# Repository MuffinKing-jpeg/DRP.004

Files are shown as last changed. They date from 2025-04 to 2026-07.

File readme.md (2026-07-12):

# DRP.004

Quack with the **new level**!
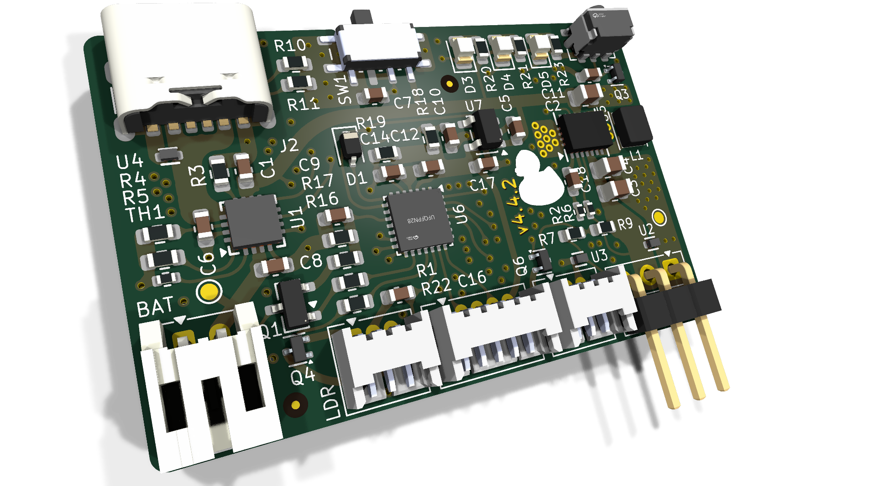
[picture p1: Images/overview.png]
bottom image


## Docs

- [Interactive BOM](./Docs/ibom.html)
- [Schematics](./Docs/DRP.004.pdf)
- [Production files](./production/)

## Changes in v3

- Completely new power design
  - 1.8v for MCU + LDR
  - ~5.5v for servo only
- Interface moved to one side.
- MOAR SILK!
- ENIG

## Changes in v4.2

- Switches moved to SMT parts
- Moved USB to same side as other user interfaces
- Changed battery connector to PH2.0
- Changed NTC thermistor to 0402
- Rerouted almost everything

## Changes in v4.3

- Threw to trash few useless resistors  
- Removed power-on by button
- Squished PCB to 27*42mm size  
- Fresh docs

## Changes in v4.4

- CI/CD
- TPS61022 -> TPS63020

## Issues to overcome

- [] Please works as v3

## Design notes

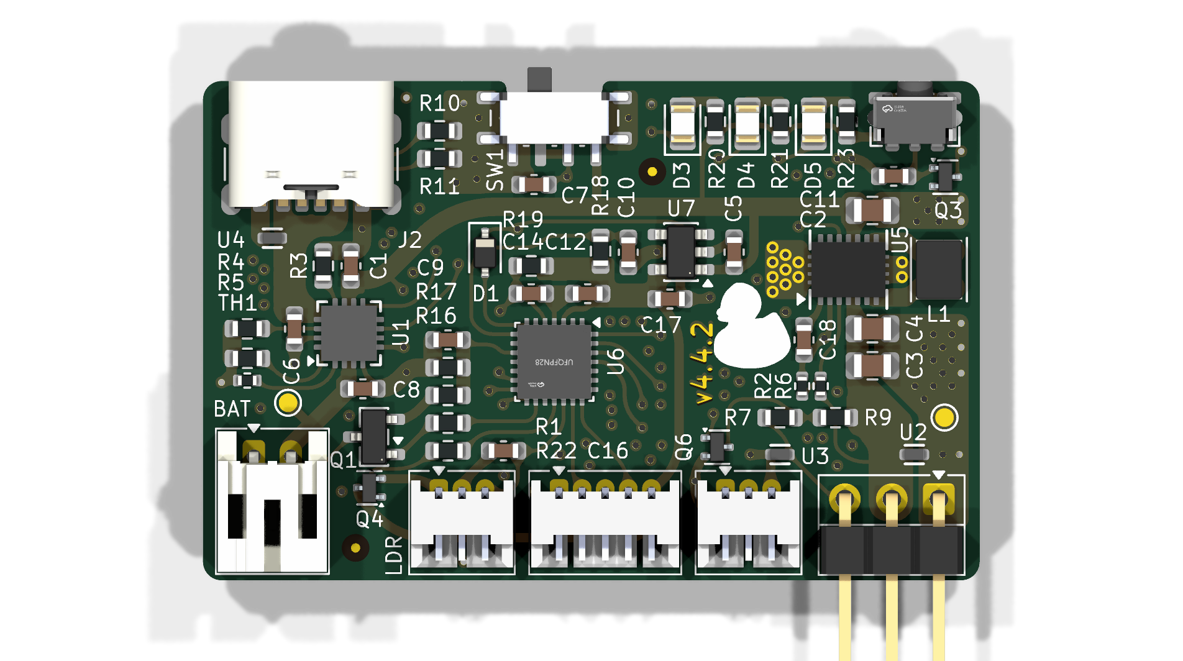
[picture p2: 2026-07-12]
Images/top.png

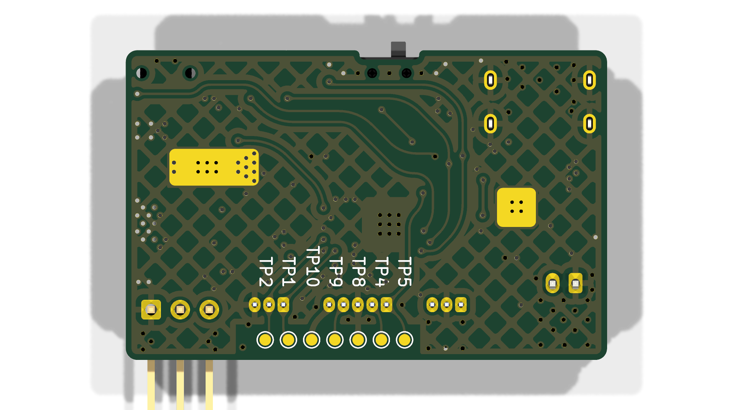
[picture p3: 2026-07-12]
Images/bot.png

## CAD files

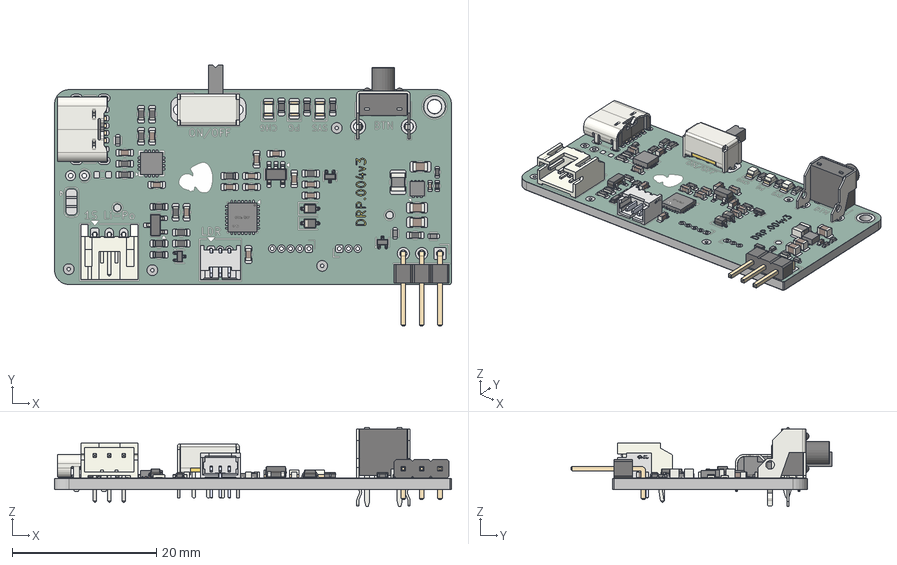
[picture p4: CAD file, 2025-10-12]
Mechanical/DRP.004.step
55.0 x 36.2 x 11.0 mm
C_0603_1608Metric x 13
R_0603_1608Metric x 17
UFQFPN-28_L4.0-W4.0-H0.6-P0.50
LED_0805_2012Metric x 3
LF x 3
CPD x 3
BODY-SON x 4
SW_Slide_SPDT_Angled_CK_OS102011MA1Q
C_0805_2012Metric x 3
CONN-TH_1.25T-3P-WP
SW_Tactile_SPST_Angled_PTS645Vx58-2LFS
USB_C_Receptacle_GCT_USB4125-xx-x-0190_6P_TopMnt_Horizontal
SOT-23
SOT-23-5
R_0402_1005Metric x 2
D_SOD-323 x 2
L_1008_2520Metric
C_0402_1005Metric
PinHeader_1x03_P2.54mm_Horizontal
JST_PH_S3B-PH-K_1x03_P2.00mm_Horizontal
BODY-QFN
PIN1-ID
DRP.004_copper
DRP.004_pad
DRP.004_via
DRP.004_silkscreen
DRP.004_soldermask
DRP.004_PCB

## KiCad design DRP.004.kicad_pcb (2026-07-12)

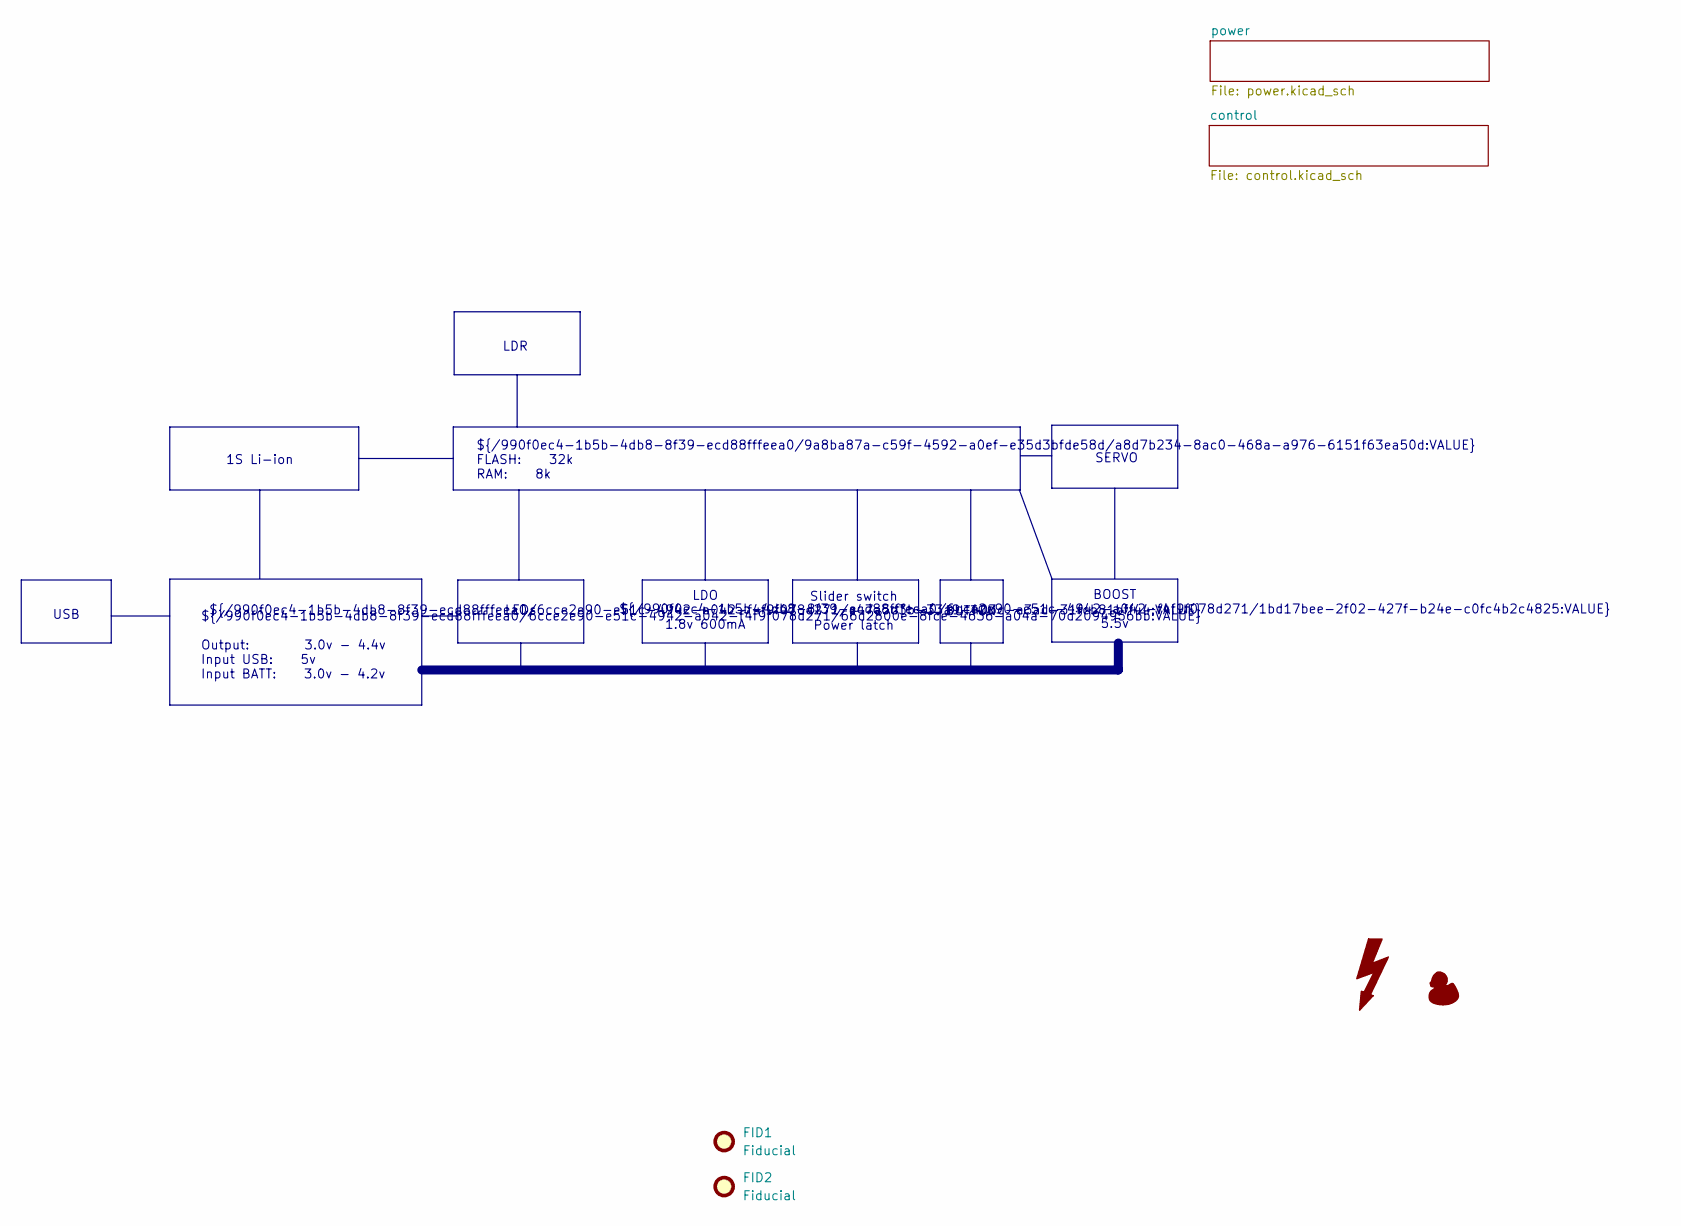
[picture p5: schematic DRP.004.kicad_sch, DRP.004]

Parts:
FID1, FID2: Fiducial; Fiducial_0.5mm_Mask1.5mm

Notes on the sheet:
Slider switch + Power latch
LEDs
SERVO
BOOST ${/990f0ec4-1b5b-4db8-8f39-ecd88fffeea0/6cce2e90-e51c-4942-a042-f4f9f078d271/1bd17bee-2f02-427f-b24e-c0fc4b2c4825:VALUE} 5.5v
USB
${/990f0ec4-1b5b-4db8-8f39-ecd88fffeea0/9a8ba87a-c59f-4592-a0ef-e35d3bfde58d/a8d7b234-8ac0-468a-a976-6151f63ea50d:VALUE} FLASH: 32k RAM: 8k
LDO ${/990f0ec4-1b5b-4db8-8f39-ecd88fffeea0/6cce2e90-e51c-4942-a042-f4f9f078d271/c47a5d3b-33a9-403c-a3ad-31fcb81bff44:VALUE} 1.8v 600mA
LDR
${/990f0ec4-1b5b-4db8-8f39-ecd88fffeea0/6cce2e90-e51c-4942-a042-f4f9f078d271/66d2800e-8fce-4636-a04a-70d2094956bb:VALUE} Output: 3.0v - 4.4v Input USB: 5v Input BATT: 3.0v - 4.2v
1S Li-ion
BUTTON

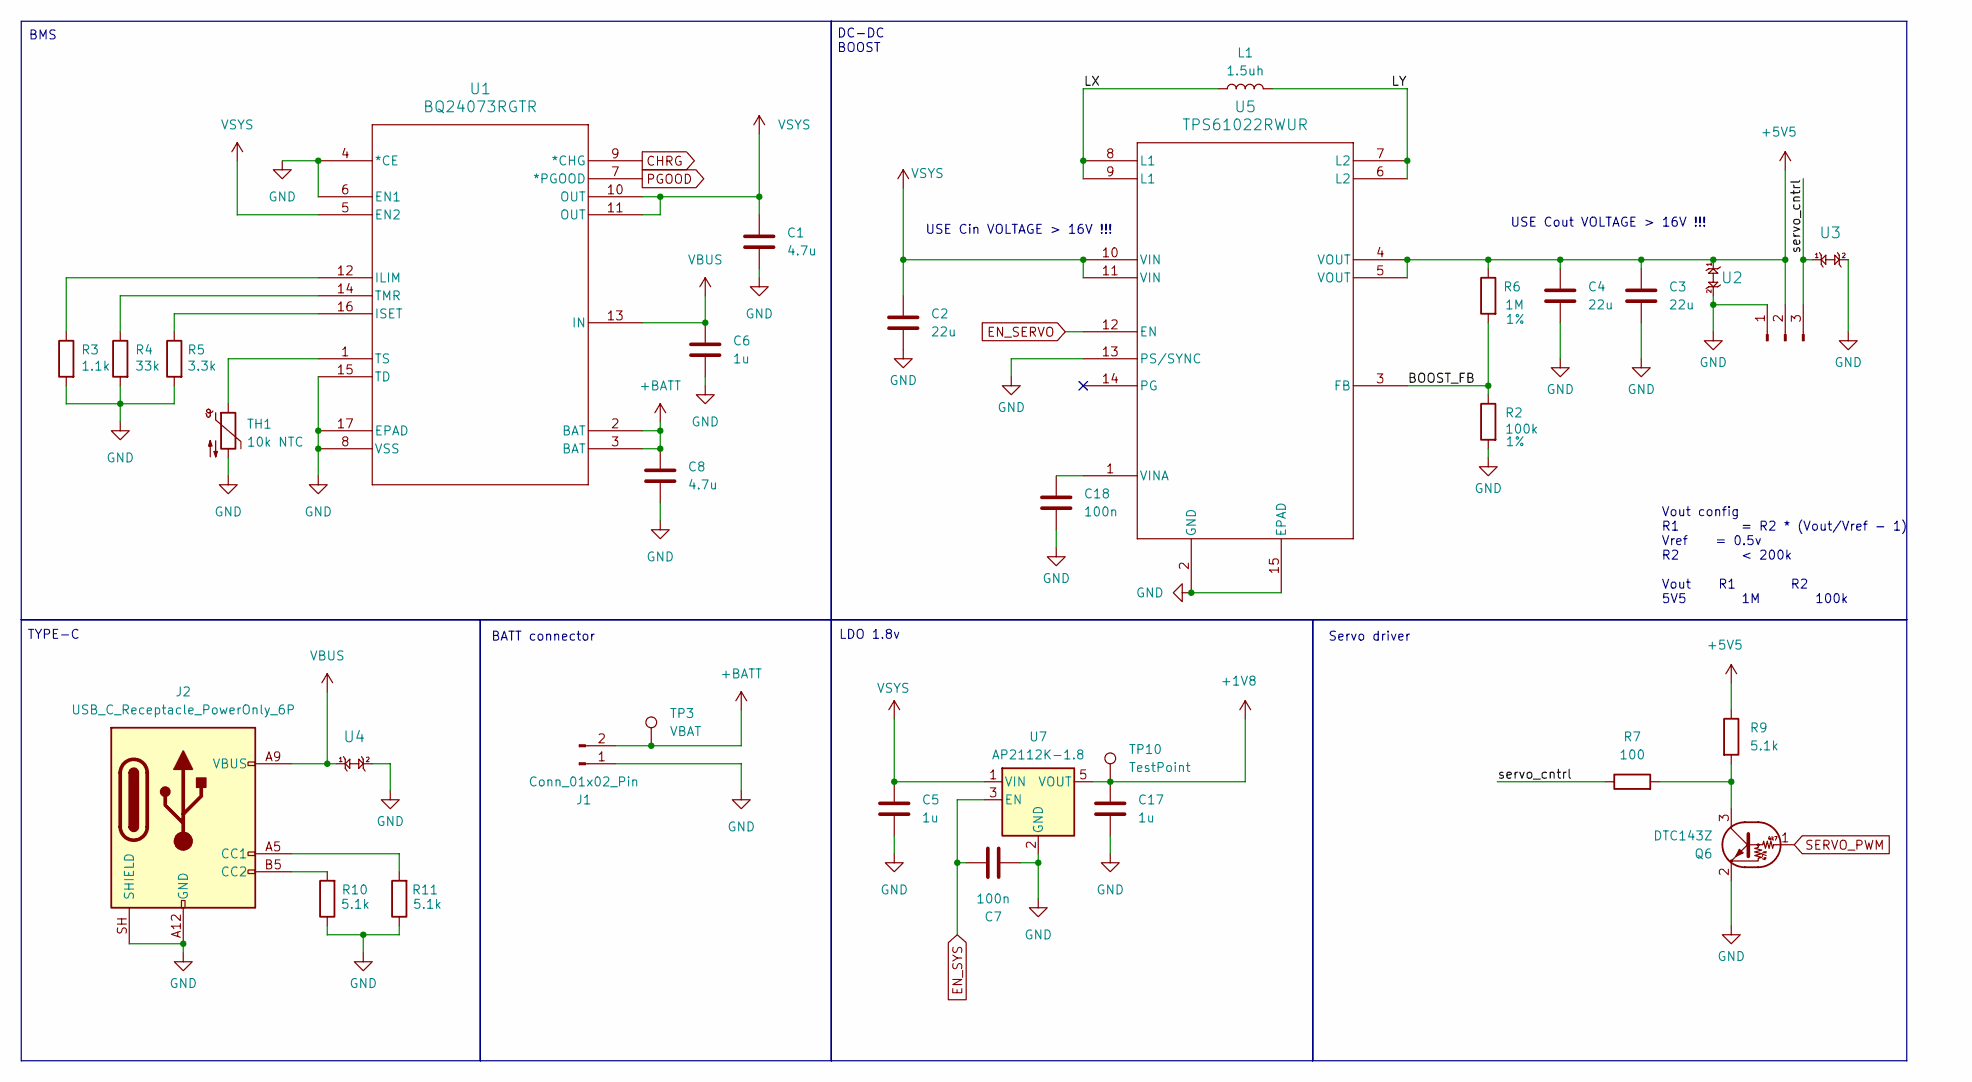
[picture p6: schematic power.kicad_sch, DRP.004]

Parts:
C1, C8: 4.7u; C_0603_1608Metric
C2, C3, C4: 22u; C_0805_2012Metric
C5, C6, C17: 1u; C_0603_1608Metric
C7, C18: 100n; C_0603_1608Metric
J1: Conn_01x02_Pin; JST_PH_S2B-PH-K_1x02_P2.00mm_Horizontal
J2: USB_C_Receptacle_PowerOnly_6P; USB_C_Receptacle_GCT_USB4125-xx-x-0190_6P_TopMnt_Horizontal
J3: Conn_01x03_Pin; PinHeader_1x03_P2.54mm_Horizontal
L1: 1.5uh; L_Changjiang_FTC322512S; LCSC C5179444
Q6: DTC143Z; SOT-523; LCSC C2828442
R2: 100k; R_0402_1005Metric; Tolerance 1%
R3: 1.1k; R_0603_1608Metric
R4: 33k; R_0603_1608Metric
R5: 3.3k; R_0603_1608Metric
R6: 1M; R_0402_1005Metric; Tolerance 1%
R7: 100; R_0603_1608Metric
R9, R10, R11: 5.1k; R_0603_1608Metric
TH1: 10k NTC; R_0402_1005Metric
TP3: VBAT; TestPoint_Pad_D1.0mm
TP10: TestPoint; TestPoint_Pad_D1.0mm
U1: BQ24073RGTR; RGT16; LCSC C15220
U2, U3, U4: TPD1E10B06DPYR; X1SON-2_L1.0-W0.6-P0.65-BI; LCSC C48260
U5: TPS61022RWUR; DSJ14_2P85X1P58; LCSC C15483
U7: AP2112K-1.8; SOT-23-5; LCSC C176944

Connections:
+1V8: C17.1, TP10.1 (1_1), U7.5 (VOUT); also elsewhere on the board
+5V5: C3.1, C4.1, J3.2, R6.1, R9.1, U2.1, U5.4 (VOUT), U5.5 (VOUT)
+BATT: C8.1, J1.2, TP3.1 (1_1), U1.2 (BAT), U1.3 (BAT); also elsewhere on the board
/power/BOOST_FB: R2.1, R6.2, U5.3 (FB)
/power/LX: L1.1, U5.8 (L1), U5.9 (L1)
/power/LY: L1.2, U5.6 (L2), U5.7 (L2)
/power/servo_cntrl: J3.3, R7.1, U3.1
CHRG: U1.9 (*CHG); also elsewhere on the board
EN_SERVO: U5.12 (EN); also elsewhere on the board
EN_SYS: C7.2, U7.3 (EN); also elsewhere on the board
GND: C1.2, C2.2, C3.2, C4.2, C5.2, C6.2, C7.1, C8.2, C17.2, C18.2, J1.1, J2.A12 (GND), J2.B12 (GND), J2.SH (SHIELD), J3.1, Q6.2 (E), R2.2, R3.2, R4.2, R5.2, R10.1, R11.1, TH1.2, U1.4 (*CE), U1.6 (EN1), U1.8 (VSS), U1.15 (TD), U1.17 (EPAD), U2.2, U3.2, U4.2, U5.2 (GND), U5.13 (PS/SYNC), U5.15 (EPAD), U7.2 (GND); also elsewhere on the board
unnamed: J2.A5 (CC1), R11.2
unnamed: J2.B5 (CC2), R10.2
unnamed: Q6.3 (C), R7.2, R9.2
unnamed: R3.1, U1.12 (ILIM)
unnamed: R5.1, U1.16 (ISET)
unnamed: R4.1, U1.14 (TMR)
unnamed: TH1.1, U1.1 (TS)
unnamed: C18.1, U5.1 (VINA)
PGOOD: U1.7 (*PGOOD); also elsewhere on the board
SERVO_PWM: Q6.1 (B); also elsewhere on the board
VBUS: C6.1, J2.A9 (VBUS), J2.B9 (VBUS), U1.13 (IN), U4.1
VSYS: C1.1, C2.1, C5.1, U1.5 (EN2), U1.10 (OUT), U1.11 (OUT), U5.10 (VIN), U5.11 (VIN), U7.1 (VIN); also elsewhere on the board

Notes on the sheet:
USE Cout VOLTAGE > 16V !!!
LDO 1.8v
DC-DC BOOST
TYPE-C
Servo driver
USE Cin VOLTAGE > 16V !!!
BMS
BATT connector
Vout config R1 = R2 * (Vout/Vref - 1) Vref = 0.5v R2 < 200k Vout R1 R2 5V5 1M 100k

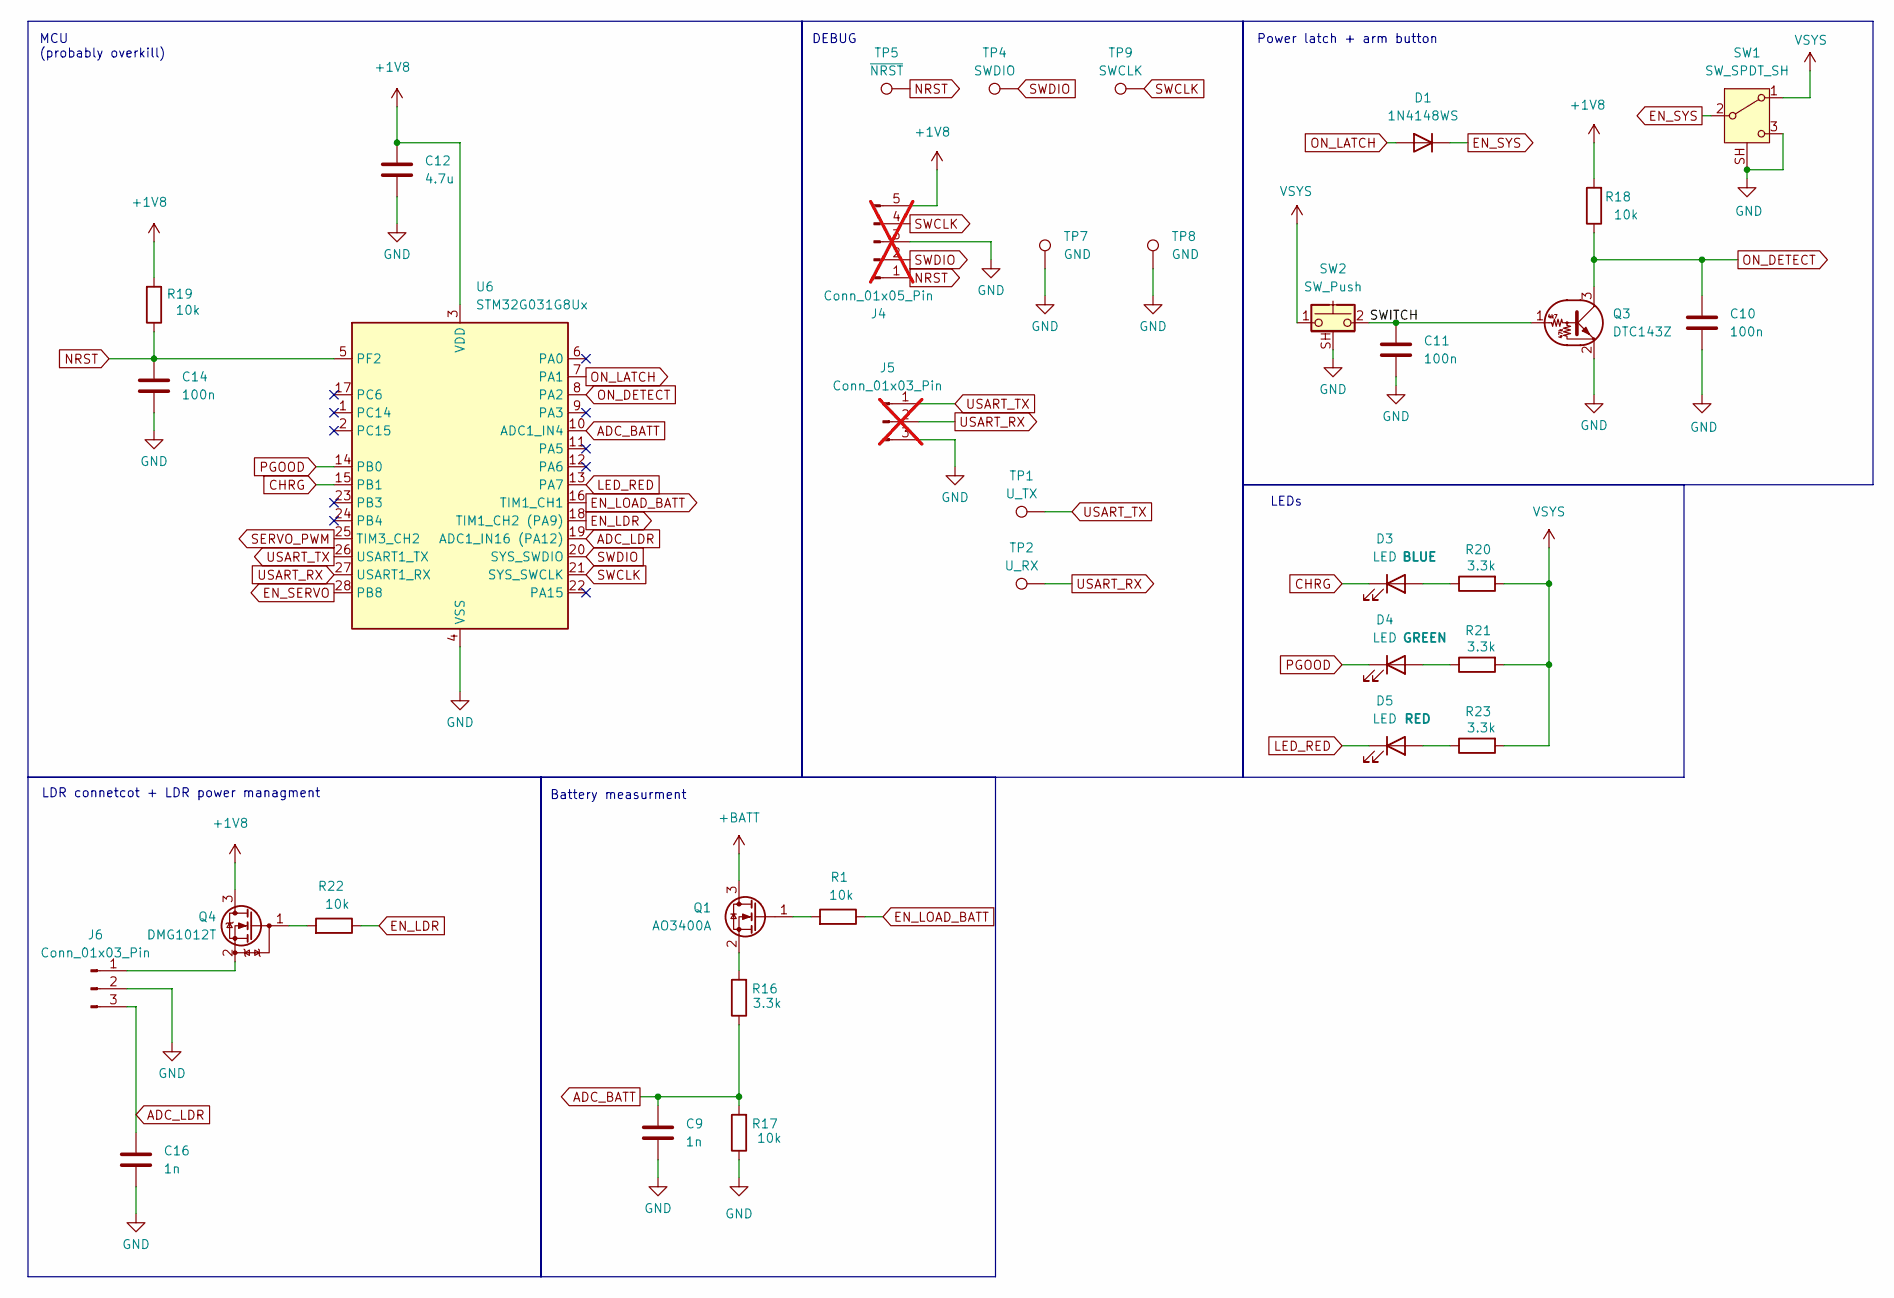
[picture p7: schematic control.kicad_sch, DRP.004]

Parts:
C9, C16: 1n; C_0603_1608Metric
C10, C11, C14: 100n; C_0603_1608Metric
C12: 4.7u; C_0603_1608Metric
D1: 1N4148WS; D_SOD-323; LCSC C6423741
D3, D4, D5: LED; LED_0805_2012Metric
J4: Conn_01x05_Pin; Molex_PicoBlade_53048-0510_1x05_P1.25mm_Horizontal; not fitted
J5: Conn_01x03_Pin; Molex_PicoBlade_53048-0310_1x03_P1.25mm_Horizontal; not fitted
J6: Conn_01x03_Pin; Molex_PicoBlade_53048-0310_1x03_P1.25mm_Horizontal
Q1: AO3400A; SOT-23
Q3: DTC143Z; SOT-523; LCSC C2828442
Q4: DMG1012T; SOT-523; LCSC C20512
R1, R17, R18, R19, R22: 10k; R_0603_1608Metric
R16, R20, R21, R23: 3.3k; R_0603_1608Metric
SW1: SW_SPDT_SH; MSK12C02; LCSC C109335
SW2: SW_Push; SW_Push_1P1T-MP_NO_Horizontal_Alps_SKRTLAE010; LCSC C398057
TP1: U_TX; TestPoint_Pad_D1.0mm
TP2: U_RX; TestPoint_Pad_D1.0mm
TP4: SWDIO; TestPoint_Pad_D1.0mm
TP5: ~{NRST}; TestPoint_Pad_D1.0mm
TP7, TP8: GND; TestPoint_Pad_D1.0mm
TP9: SWCLK; TestPoint_Pad_D1.0mm
U6: STM32G031G8Ux; QFN-28_4x4mm_P0.5mm; LCSC C432211

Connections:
+1V8: C12.1, J4.5, Q4.3 (D), R18.2, R19.2, U6.3 (VDD); also elsewhere on the board
+BATT: Q1.3 (D); also elsewhere on the board
/control/SWITCH: C11.1, Q3.1 (B), SW2.2
ADC_BATT: C9.1, R16.1, R17.2, U6.10 (ADC1_IN4)
ADC_LDR: C16.1, J6.3, U6.19 (ADC1_IN16 (PA12))
CHRG: D3.1 (K), U6.15 (PB1); also elsewhere on the board
EN_LDR: R22.1, U6.18 (TIM1_CH2 (PA9))
EN_LOAD_BATT: R1.1, U6.16 (TIM1_CH1)
EN_SERVO: U6.28 (PB8); also elsewhere on the board
EN_SYS: D1.1 (K), SW1.2 (B); also elsewhere on the board
GND: C9.2, C10.2, C11.2, C12.2, C14.2, C16.2, J4.3, J5.3, J6.2, Q3.2 (E), R17.1, SW1.3 (C), SW1.SH (Shield), SW2.SH (B), TP7.1 (1_1), TP8.1 (1_1), U6.4 (VSS); also elsewhere on the board
LED_RED: D5.1 (K), U6.13 (PA7)
NRST: C14.1, J4.1, R19.1, TP5.1 (1_1), U6.5 (PF2)
unnamed: D3.2 (A), R20.1
unnamed: D4.2 (A), R21.1
unnamed: D5.2 (A), R23.1
unnamed: J6.1, Q4.2 (S)
unnamed: Q1.1 (G), R1.2
unnamed: Q1.2 (S), R16.2
unnamed: Q4.1 (G), R22.2
ON_DETECT: C10.1, Q3.3 (C), R18.1, U6.8 (PA2)
ON_LATCH: D1.2 (A), U6.7 (PA1)
PGOOD: D4.1 (K), U6.14 (PB0); also elsewhere on the board
SERVO_PWM: U6.25 (TIM3_CH2); also elsewhere on the board
SWCLK: J4.4, TP9.1 (1_1), U6.21 (SYS_SWCLK)
SWDIO: J4.2, TP4.1 (1_1), U6.20 (SYS_SWDIO)
USART_RX: J5.2, TP2.1 (1_1), U6.27 (USART1_RX)
USART_TX: J5.1, TP1.1 (1_1), U6.26 (USART1_TX)
VSYS: R20.2, R21.2, R23.2, SW1.1 (A), SW2.1; also elsewhere on the board

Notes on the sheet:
MCU (probably overkill)
DEBUG
LEDs
LDR connetcot + LDR power managment
Power latch + arm button
Battery measurment

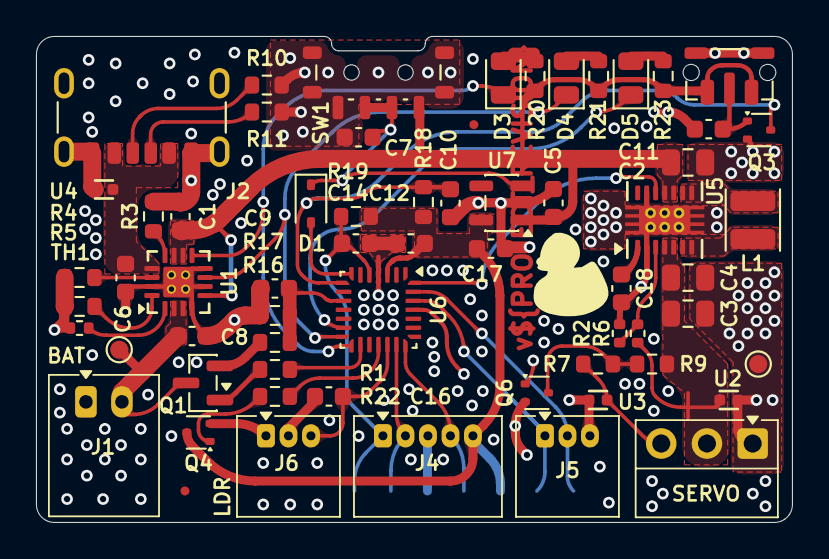
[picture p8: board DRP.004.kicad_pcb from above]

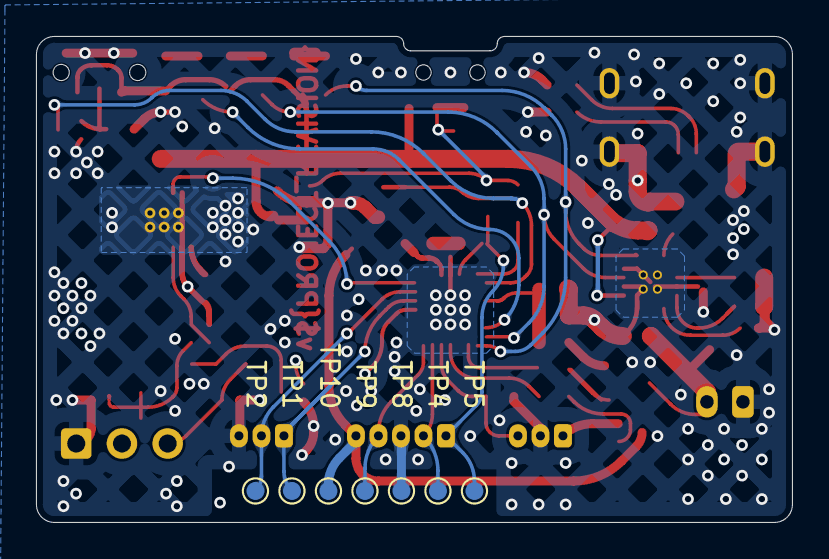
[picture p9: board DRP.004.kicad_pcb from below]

Board: 4 copper layers, 42.0 x 27.0 mm, 70 parts (7 on the bottom side), 43 nets.

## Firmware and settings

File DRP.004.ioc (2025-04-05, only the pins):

Mcu.UserName=STM32G031G8Ux
PA0.GPIO_Label=MODE_SW
PA0.Signal=GPIO_Output
PA1.GPIO_Label=LOAD_BATT
PA1.Signal=GPIO_Output
PA13.Signal=SYS_SWDIO
PA14-BOOT0.Signal=SYS_SWCLK
PA2.GPIO_Label=ADC_BATT
PA2.Signal=ADC1_IN2
PA3.GPIO_Label=ON_LATCH
PA3.Signal=GPIO_Output
PA4.GPIO_Label=WAKEUP
PA4.Signal=SYS_WKUP2
PA5.GPIO_Label=HID_LED
PA5.Signal=S_TIM2_CH1_ETR
PA7.GPIO_Label=ADC_LDR
PA7.Signal=ADC1_IN7
PB1.GPIO_Label=LDR_ON
PB1.Signal=GPIO_Output
PB6.Signal=USART1_TX
PB7.Signal=USART1_RX
PB8.GPIO_Label=PWM_SERVO
PB8.Signal=S_TIM16_CH1
PC6.GPIO_Label=PMIC_PGOOD
PC6.Signal=GPIO_Input

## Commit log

2025-04-05 Init commit
    [DLA0010A.stp, DPY0002A.stp, DRP.004.kicad_pcb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]
2025-04-06 v1 Revision - Better routing - Added testpoints - DUCK - Tweaked drawings
    [DRP.004.kicad_sch, bom.csv, control.kicad_sch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]
2025-04-08 v2 Rev
    [DRP.004.kicad_pcb, DRP.004.kicad_sch, bom.csv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]
2025-04-09 Removed C5 Improved layout
    [DRP.004.kicad_pcb, DRP.004.kicad_sch, power.kicad_sch]
2025-04-09 Return of the duck!
    [DRP.004.kicad_pcb]
2025-04-09 Made prettier look
    [DRP.004.kicad_pcb, control.kicad_sch]
2025-04-10 Some cleanup
    [DRP.004.kicad_pcb]
2025-04-19 Beautify placements (R20 R21 R23)
    [DRP.004.kicad_pcb, bom.csv, designators.csv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]
2025-04-20 Increased openings under PMICs
    [DRP.004.kicad_pcb, DRP.004.kicad_sch, control.kicad_sch]
2025-05-07 Buffed MOSFETs - Changed Q1,Q2 to AO3400 - Changed Q4 to DMG1012T
    [DRP.004.kicad_pcb, DRP.004.kicad_sch, control.kicad_sch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]
2025-05-07 Uodated production files
    [DRP.004.kicad_sch, bom.csv, positions.csv]
2025-05-31 Adjusted stencil for custom jig
    [DRP.004.kicad_pcb, DRP.004.kicad_sch, bom.csv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]
2025-09-10 Removed PART folder
    [DLA0010A.stp, DPY0002A.stp, RGT0016B.stp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]
2025-09-15 Rough placment of components for v3
    [DRP.004.kicad_pcb, control.kicad_sch, power.kicad_sch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]
2025-09-15 Routed v3
    [DRP.004.kicad_pcb, DRP.004.kicad_sch, control.kicad_sch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]
2025-09-16 Finished v3
    [DRP.004.kicad_pcb, DRP.004.kicad_sch, control.kicad_sch]
2025-09-16 Moved servo logic to 5v
    [DRP.004.kicad_pcb, DRP.004.kicad_sch, power.kicad_sch]
2025-09-17 Added stencil outline
    [DRP.004.kicad_pcb, control.kicad_sch]
2025-09-17 Expanded documentation
    [DRP.004.kicad_pcb, DRP.004.kicad_sch, control.kicad_sch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]
2025-09-18 Updated schematics. Calculated inductor values
    [DRP.004.kicad_pcb, DRP.004.kicad_sch, control.kicad_sch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]
2025-09-19 Prepeared production files
    [DRP.004.kicad_pcb, bom.csv, control.kicad_sch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]
2025-09-21 Cleaned up libs
    [DRP.004.kicad_pcb, DRP.004.kicad_sch, control.kicad_sch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]
2025-09-21 Updated footprints
    [DRP.004.kicad_pcb]
2025-10-11 Updated production data and docs
    [DRP.004.csv, DRP.004.step, bom.csv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]
2025-10-18 Updated project jobset - Added generation of ibom - Updated production files
    [DRP.004.kicad_pcb, control.kicad_sch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]
2025-12-14 V4 revision - Moved usb to HID side - Changed battery connector to ph2.0 with standard(ish) pinout - Better footprints for debug and ldr connectors - Changed switch from SK12D07 to MSK12C02 - Changed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
    [DRP.004.csv, DRP.004.kicad_pcb, DRP.004.kicad_sch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]
2025-12-28 v4.1 - Changed SW2 to SMT (with lower profile) - Widen annular ring of vias - Small changes in routing (due to wider vias)
    [DRP.004.csv, DRP.004.kicad_pcb, control.kicad_sch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]
2025-12-28 v4.2 Revision - Rerouting again - New SW2
    [DRP.004.csv, DRP.004.kicad_pcb, DRP.004.kicad_sch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]
2026-03-15 v4.3 - Smaller, faster, stronger (lol) - Removed few appendixes - Updated doc jobs set
    [DRP.004.csv, DRP.004.kicad_pcb, DRP.004.kicad_sch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]
2026-06-08 Updated files in KiCAD 10.0.3
    [DRP.004.kicad_pcb]
2026-06-08 Updated release project to new flow
    [DRP.004.csv, DRP.004.kicad_pcb, DRP.004.kicad_sch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]
2026-06-08 Some black magic (probably) to fix segfaults
    [DRP.004.kicad_pcb]
2026-06-09 Tweaked stencil outline. Probably, hopefully, theoretically fixed CI
    [DRP.004.kicad_pcb]
2026-07-12 Fixed 3D model path resolution
    [DRP.004.kicad_pcb]
2026-07-12 v4.4.1 Beatified pcb, balanced coper, version bump
    [DRP.004.kicad_pcb, DRP.004.kicad_sch, control.kicad_sch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]
